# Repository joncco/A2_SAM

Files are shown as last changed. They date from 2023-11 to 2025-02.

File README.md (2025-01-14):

# A2_SAM
Clone of the Software Automatic Mouth card for Apple II.  Despite being supposedly "software only speech synthesizer", the Apple II version required a card containing a DAC.  A hack exists that does not need the card and uses the internal speaker, but this one has a lot of distortion.

SAM_libraries contain schematic symbols and footprints that are not in the standard kicad libraries.

SAM.zip contains the gerbers for the latest release.

Updates:

06/01/2025
Fixed slot dimensions (original was too big)

Removed solder mask from area around slot pins.
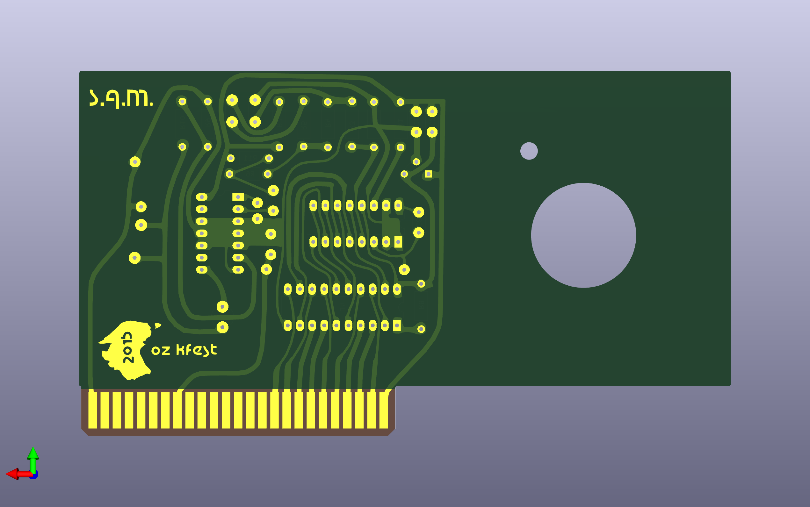
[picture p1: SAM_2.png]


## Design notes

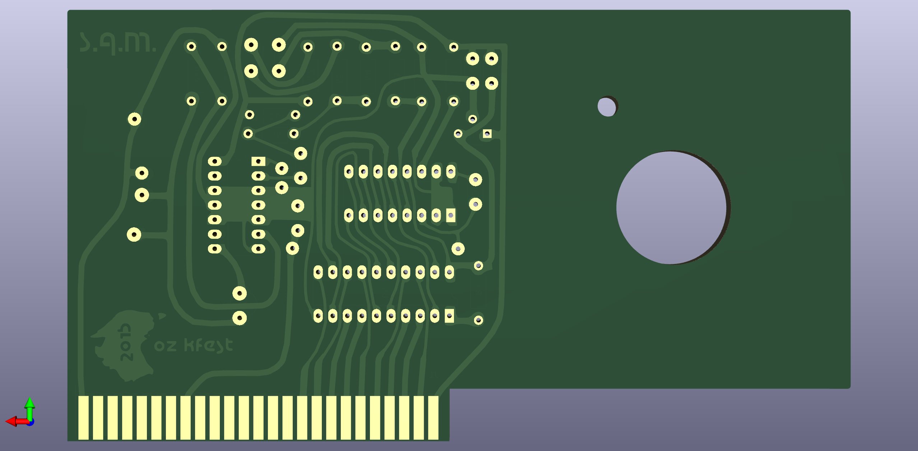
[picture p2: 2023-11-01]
SAM.png

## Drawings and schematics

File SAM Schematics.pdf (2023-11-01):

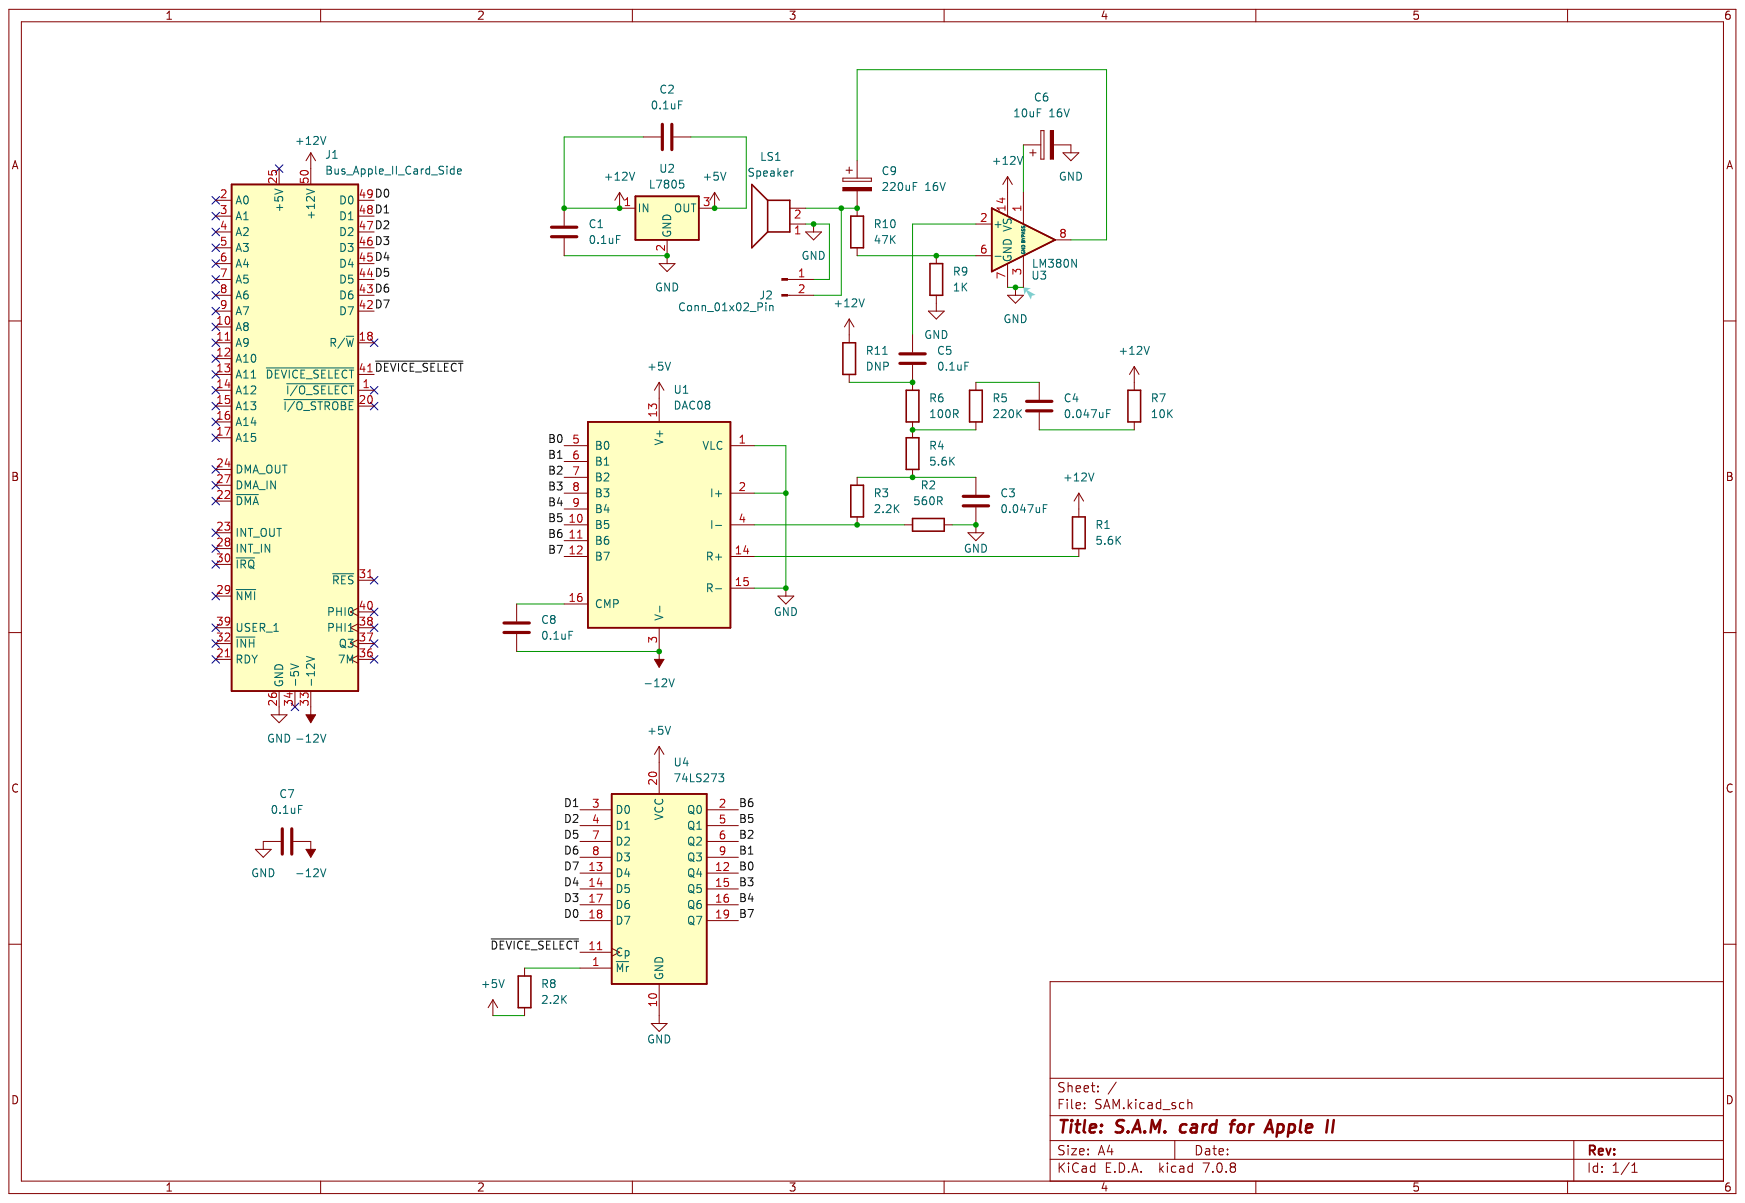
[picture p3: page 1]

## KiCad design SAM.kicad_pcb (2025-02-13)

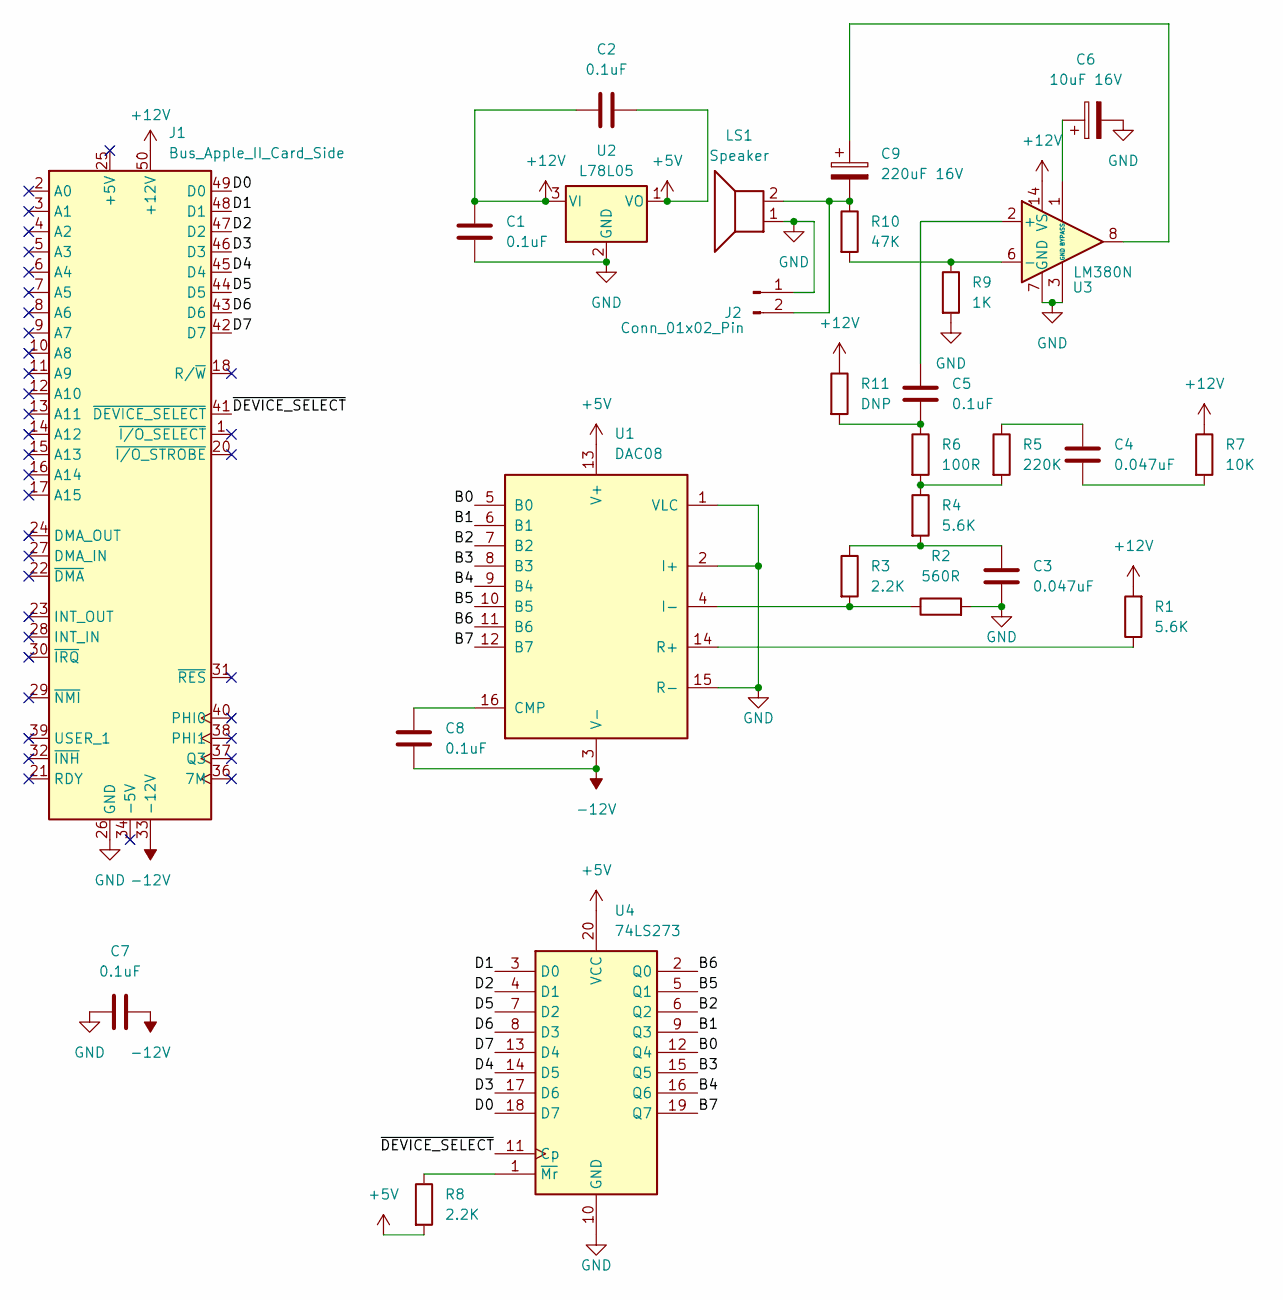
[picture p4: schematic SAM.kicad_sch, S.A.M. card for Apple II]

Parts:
C1, C2, C5, C7, C8: 0.1uF; Ceramic_CAP1
C3, C4: 0.047uF; Ceramic_CAP2
C6: 10uF 16V; CP_Radial_Tantal_D4.5mm_P3.7
C9: 220uF 16V; CP_Radial_Tantal_D4.5mm_P4.3
J1: Bus_Apple_II_Card_Side; BUS_A2
J2: Conn_01x02_Pin; PinHeader_1x02_P1.27mm_Horizontal
LS1: Speaker
R1, R4: 5.6K; R_Axial_DIN0207_L6.3mm_D2.5mm_P9.5mm_Horizontal
R2: 560R; R_Axial_DIN0207_L6.3mm_D2.5mm_P9.5mm_Horizontal
R3, R8: 2.2K; R_Axial_DIN0207_L6.3mm_D2.5mm_P9.5mm_Horizontal
R5: 220K; R_Axial_DIN0207_L6.3mm_D2.5mm_P9.5mm_Horizontal
R6: 100R; R_Axial_DIN0207_L6.3mm_D2.5mm_P8.0mm_Horizontal
R7: 10K; R_Axial_DIN0207_L6.3mm_D2.5mm_P9.5mm_Horizontal
R9: 1K; R_Axial_DIN0207_L6.3mm_D2.5mm_P9.5mm_Horizontal
R10: 47K; R_Axial_DIN0207_L6.3mm_D2.5mm_P9.5mm_Horizontal
R11: DNP; R_Axial_DIN0207_L6.3mm_D2.5mm_P8.0mm_Horizontal
U1: DAC08; DIP-16_W7.62mm_LongPads
U2: L78L05; TO-92_Inline
U3: LM380N; DIP-14_W7.62mm_LongPads
U4: 74LS273; DIP-20_W7.62mm_LongPads

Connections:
+5V: C2.2, R8.2, U1.13 (V+), U2.1 (VO), U4.20 (VCC)
+12V: C1.1, C2.1, J1.50 (+12V), R1.2, R7.1, R11.1, U2.3 (VI), U3.14 (VS)
-12V: C7.2, C8.2, J1.33 (-12V), U1.3 (V-)
/B0: U1.5 (B0), U4.12 (Q4)
/B1: U1.6 (B1), U4.9 (Q3)
/B2: U1.7 (B2), U4.6 (Q2)
/B3: U1.8 (B3), U4.15 (Q5)
/B4: U1.9 (B4), U4.16 (Q6)
/B5: U1.10 (B5), U4.5 (Q1)
/B6: U1.11 (B6), U4.2 (Q0)
/B7: U1.12 (B7), U4.19 (Q7)
/D0: J1.49 (D0), U4.18 (D7)
/D1: J1.48 (D1), U4.3 (D0)
/D2: J1.47 (D2), U4.4 (D1)
/D3: J1.46 (D3), U4.17 (D6)
/D4: J1.45 (D4), U4.14 (D5)
/D5: J1.44 (D5), U4.7 (D2)
/D6: J1.43 (D6), U4.8 (D3)
/D7: J1.42 (D7), U4.13 (D4)
/~DEVICE_SELECT: J1.41 (~DEVICE_SELECT), U4.11 (Cp)
GND: C1.2, C3.2, C6.2, C7.1, J1.26 (GND), J2.1, LS1.1, R2.2, R9.2, U1.1 (VLC), U1.2 (I+), U1.15 (R-), U2.2 (GND), U3.3 (GND), U3.4 (GND), U3.5 (GND), U3.7 (GND), U3.10 (GND), U3.11 (GND), U3.12 (GND), U4.10 (GND)
unnamed: C3.1, R3.1, R4.2
unnamed: C4.1, R5.1
unnamed: C4.2, R7.2
unnamed: C5.2, R6.1, R11.2
unnamed: C9.1, U3.8
unnamed: C9.2, J2.2, LS1.2, R10.1
unnamed: R4.1, R5.2, R6.2
unnamed: C8.1, U1.16 (CMP)
unnamed: R2.1, R3.2, U1.4 (I-)
unnamed: R1.1, U1.14 (R+)
unnamed: C5.1, U3.2 (+)
unnamed: R9.1, R10.2, U3.6 (-)
unnamed: C6.1, U3.1 (BYPASS)
unnamed: R8.1, U4.1 (~Mr)

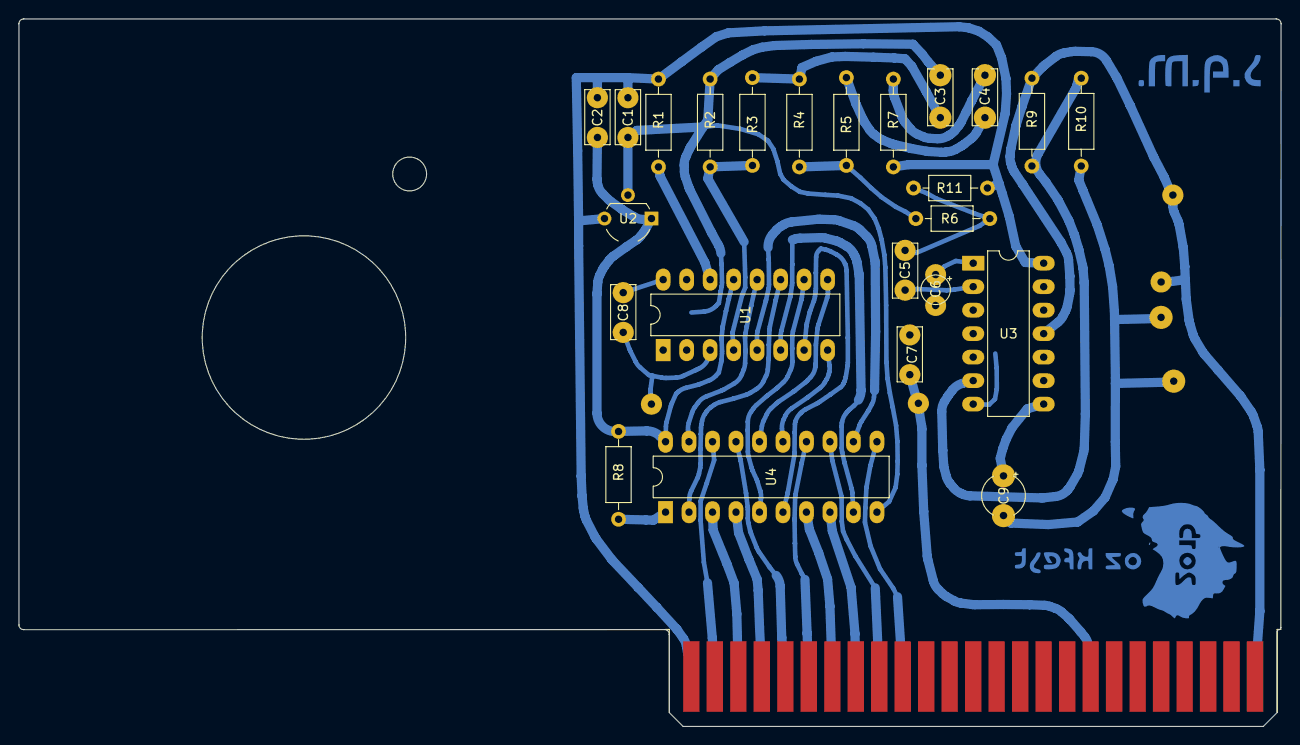
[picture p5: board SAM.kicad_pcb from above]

Board: 2 copper layers, 136.5 x 76.5 mm, 25 parts (0 on the bottom side), 35 nets.

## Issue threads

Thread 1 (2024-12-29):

Remove solder mask from edge card connector area.

joncco, 2024-12-29:
Slot edge card connector areas need to be free from solder mask or there is risk it will come off inside user's slot over time.

Closed 2025-01-06.

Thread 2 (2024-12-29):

Check slot edge card connector measurements.

joncco, 2024-12-29:
Slot edge card connector may be too big for some Apple II slots..

joncco, 2025-01-06:
based on this datasheet https://www.mouser.com/datasheet/2/418/6/ENG_CD_2358256_A-2045950.pdf

The dimensions of the pcb "dimension D" should be 65.74, so this is obviously too big.

Closed 2025-01-06.

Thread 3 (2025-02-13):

L7805 (U2) should this be 78L05?

6800legacy, 2025-02-13:
Hi just noticed the L7805 (U2) part has a 78L05 component outline that has the input (12v) on Pin 1 and output on Pin 3 (based on the component outline should be reversed to use a TO-92? ) should this be a 78L05 TO-92 with the flat edge on top or do you recommend using a L7805?

Also would this card allow connecting the Apple II speaker(line) out from motherboard to go through the cards speaker hence having all sound output through the card?

Thank you for your work

joncco, 2025-02-13:
Looks like a typo.  Original card did use a 78L05 with flat side on top.

This is the clone of a card and there was no provision to pass Apple II speaker through.

Closed 2025-02-13.

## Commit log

2023-11-01 Add files for human readable schematic and PCB image
2023-11-01 chamfer traces so they look like manually done
    [SAM.kicad_pcb]
2023-11-02 Update speaker hole diameter
    [SAM.kicad_pcb]
2023-11-06 Update remove solder mask from ozkfest and sam logo
    [SAM.kicad_pcb]
2025-01-06 Fix Apple II slot dimensions
    [SAM.kicad_pcb]
2025-01-06 Replot gerber file
2025-01-06 Rerender board with latest changes
2025-02-13 change 7805 to 78L05
    [SAM.kicad_pcb, SAM.kicad_sch]
